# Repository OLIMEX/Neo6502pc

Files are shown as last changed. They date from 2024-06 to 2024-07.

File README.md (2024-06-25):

# Neo6502pc
World fastest 6502 computer. All in one Open Source Hardware and Software Modern Retro computer with real 6502 processor, HDMI, USB Flash drive, USB Gamepads, mouse, Keyboard support.

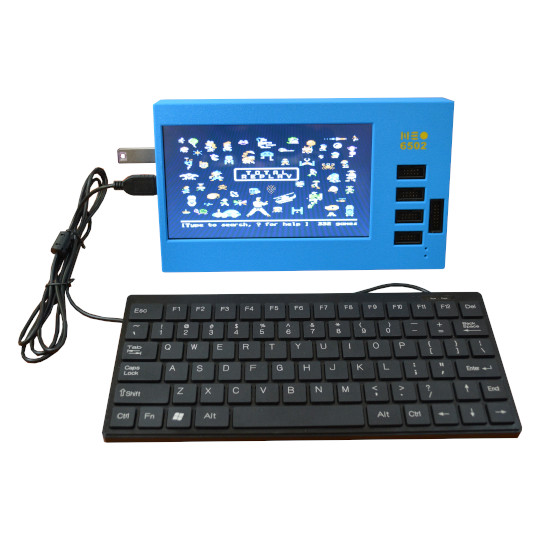
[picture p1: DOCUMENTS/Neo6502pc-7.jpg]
Neo6502pc-1


https://www.olimex.com/Products/Retro-Computers/Neo6502pc/open-source-hardware

## Licensee
* Hardware is released under CERN Open Hardware Licence Version 2 - Strongly Reciprocal
* Software is released under GPL V3 Licensee
* Documentation is released under CC BY-SA 4.0

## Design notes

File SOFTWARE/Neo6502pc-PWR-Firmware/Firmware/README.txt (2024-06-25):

### Install - packages
apt-get install build-essential libnewlib-dev gcc-riscv64-unknown-elf libusb-1.0-0-dev libudev-dev gdb-multiarch

### Install - Visual Studio Code 
https://code.visualstudio.com/docs/setup/linux

### Install - Platform IO 
https://platformio.org/install/ide?install=vscode

### Install - CH32V-Platform
https://github.com/Community-PIO-CH32V/ch32-pio-projects?tab=readme-ov-file#installing-the-ch32v-platform

To build firmware.bin and firmware.elf select 
> PlatformIO > PROJECT TASKS > Default > Advanced > Verbose build

Usage
===================================

I2C address - 0x33

Registers
-----------------------------------
0x00 - API version (major)
0x01 - API version (minor)
0x02 - Pin select
0x03 - GPIO config
       0x00 - output open drain
       0x01 - output push pull
       0x80 - input float
       0x81 - input pull down
       0x82 - input pull up
0x04 - Data
0x05 - Pins as bits MSB 
0x06 - Pins as bits LSB 
0x07 - BATSENS in percent 
0x08 - BATSENS in mV MSB 
0x09 - BATSENS in mV LSB 

All pins are initally configured as inputs pull down.
NOTE: Valid pins are from 3 to 14. 
NOTE: Virtual pin 15 is PWRSENS.
NOTE: VBAT range 3.2V - 4.2V => BATSENS range 0.89V - 1.14V

To change configuration:
------------------------
1. Write to register 0x02 (Pin select) pin you want to configure
2. Write to register 0x03 (GPIO config) desired config value

To get pin state:
-----------------
1. Write to register 0x02 (Pin select) pin you want to check
2. Read register 0x04 (Data)
If the pin is configured as input (default) readed value is current pin state
If the pin is configured as output the value is last set state

To change pin state:
--------------------
1. Write to register 0x02 (Pin select) pin you want to change
2. Write to register 0x04 (Data) desired new state
If the pin is configured as input (default) nothing will be done
If the pin is configured as output the pin state will be set

Alternative method:
--------------------
You can use registers 0x05 and 0x06 to get/set pin state at once
Register 0x05 contains MSB - pins 15 - 8
Register 0x06 contains LSB - pins  7 - 0

NOTE: Valid pins are from 3 to 14.
NOTE: Virtual pin 15 is PWRSENS.

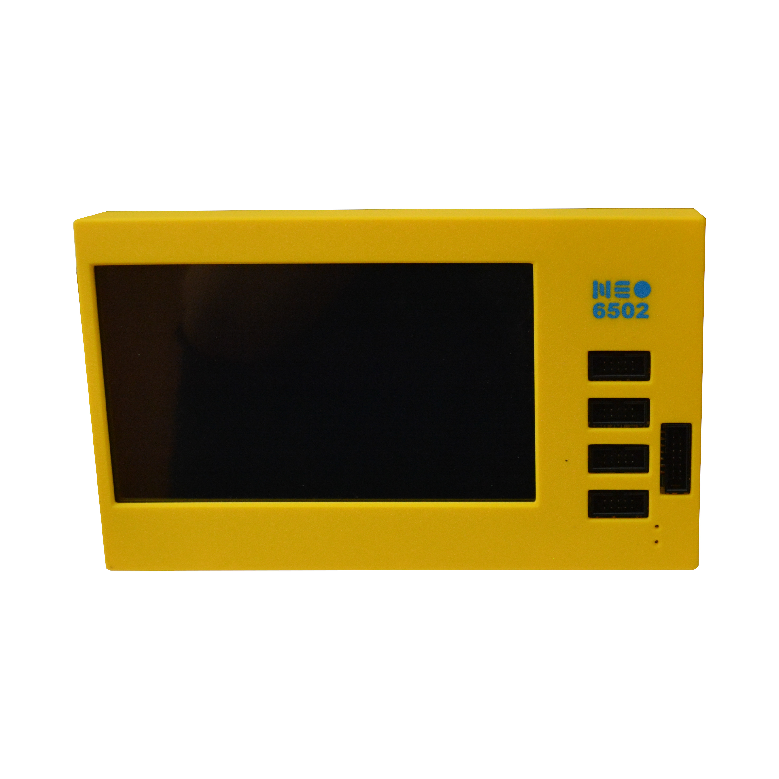
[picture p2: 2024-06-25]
DOCUMENTS/Neo6502pc-9.jpg

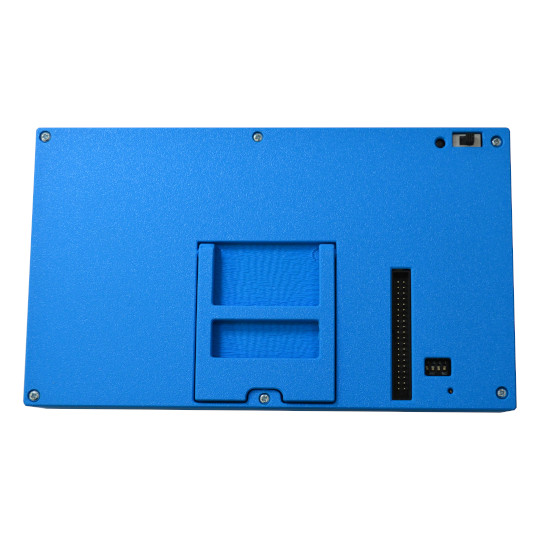
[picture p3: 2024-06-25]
DOCUMENTS/Neo6502pc-2.jpg

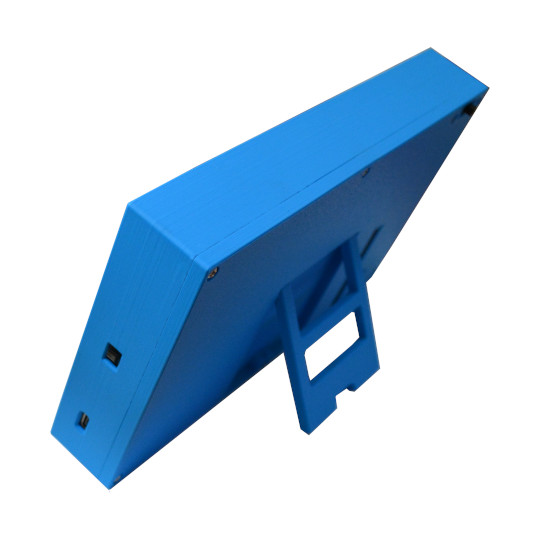
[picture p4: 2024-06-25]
DOCUMENTS/Neo6502pc-5.jpg

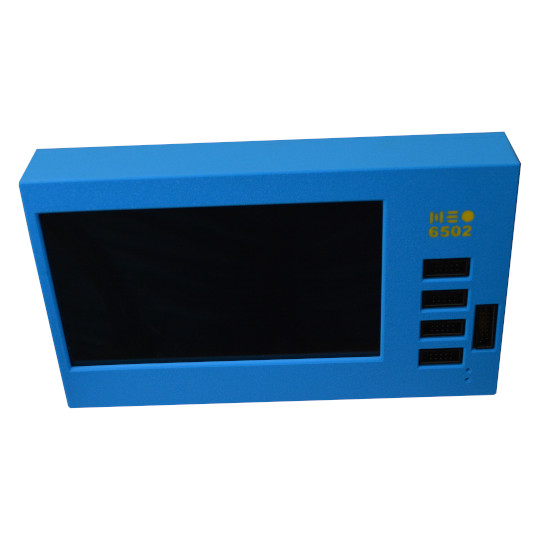
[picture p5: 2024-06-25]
DOCUMENTS/Neo6502pc-6.jpg

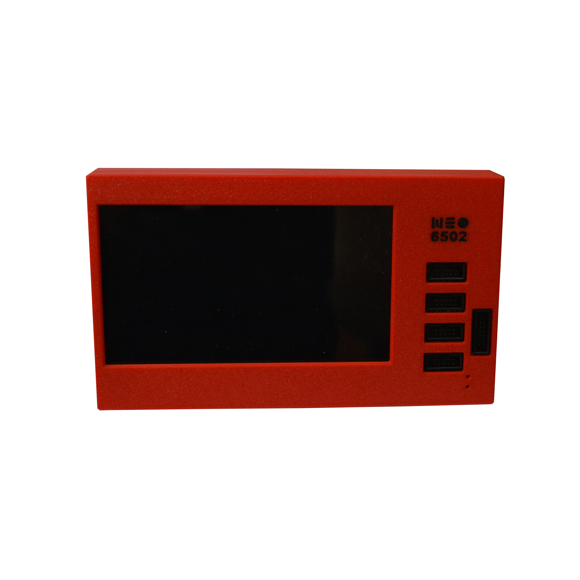
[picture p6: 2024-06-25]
DOCUMENTS/Neo6502pc-10.jpg

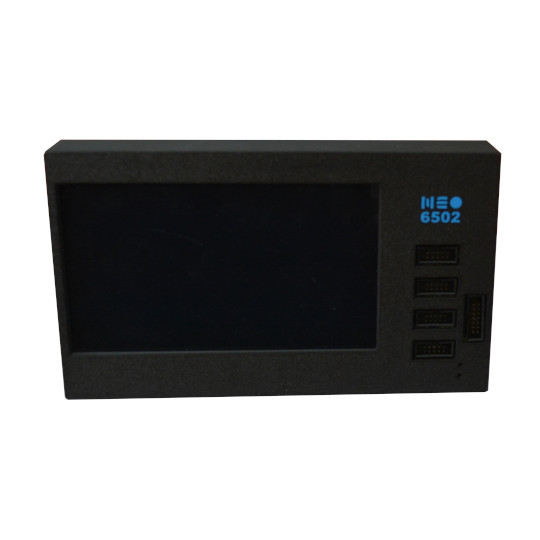
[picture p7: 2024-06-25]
DOCUMENTS/Neo6502pc-11.jpg

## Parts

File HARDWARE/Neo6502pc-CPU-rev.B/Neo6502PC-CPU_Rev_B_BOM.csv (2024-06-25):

Quantity | Value | Footprint | Reference
1 | PJ-3.5-365-5P | SCJ325P00XG0B02G | AUDIO1
1 | T1102D(6x6x9.5mm) | T1102D_6x6 | BOOT1
1 | P-B-V-40-LF | GBH-254-SMT-40 | BUS1
19 | 100nF/10V/20%/X5R/C0402 | C_0402_5MIL_DWS | C1, C2, C3, C4, C5, C6, C7, C8, C9, C10, C13, C14, C20, C24, C30, C31, C33, C34, C36
5 | 2.2uF/6.3V/20%/X5R/C0402 | C_0402_5MIL_DWS | C11, C12, C32, C35, C37
2 | 18pF/50V/5%/C0G/C0402 | C_0402_5MIL_DWS | C15, C16
3 | 47uF/6.3V/20%/X5R/C0805 | C_0805_5MIL_DWS | C17, C27, C28
1 | 1uF/10V/10%/X5R/C0603 | C_0603_5MIL_DWS | C18
1 | 10uF/6.3V/20%/X5R/C0603 | C_0603_5MIL_DWS | C19
2 | 22uF/6.3V/20%/X5R/C0603 | C_0603_5MIL_DWS | C23, C29
1 | CABLE PH2.0-3 | Cable-IDC | Cable-PWR1
1 | pUEXT-CABLE-10-10-200MM | Cable-IDC | Cable-pUEXT1
1 | 1N4148W/SOD123 | SOD-123_1C-2A_KA | D1
1 | HDMI-SWM-19 | HDMI-SWM-19_Paste | DVI1
1 | FSMD035-1206 | FUSE-1206 | FUSE1
1 | SS-12D10L5 | SS-12D10L5 | HUB_RST_OFF/ON1
1 | PH2.0-3PWB | PH2.0-3PWB | PWR_In/Out1
2 | Q12MHz/20pF/10ppm/4P/3.2x2.5mm | TSX-3.2x2.5mm_GND(3) | Q1, Q3
1 | BC817-40(SOT23) | SOT23 | Q2
10 | 10k/R0402 | R_0402_5MIL_DWS | R1, R12, R13, R14, R15, R16, R17, R26, R27, R28
2 | 100R/R0402 | R_0402_5MIL_DWS | R3, R6
2 | 27R/R0402 | R_0402_5MIL_DWS | R4, R5
1 | 33k/R0402 | R_0402_5MIL_DWS | R7
1 | 150R/R0402 | R_0402_5MIL_DWS | R8
1 | 47R/R1206 | R_1206_5MIL_DWS | R9
3 | 2.2k/R0402 | R_0402_5MIL_DWS | R10, R29, R30
9 | 270R/R0402 | R_0402_5MIL_DWS | R11, R18, R19, R20, R21, R22, R23, R24, R25
2 | 5.1k/1%/R0402 | R_0402_5MIL_DWS | R31, R32
2 | RA1206_(4x0603)_4B8_330R | RA1206_(4X0603)_4B8_xx | RM1, RM2
1 | Speaker_QMB-09B-03(1.5-5.0V_2.7kHz_F9.0mm*H5.5mm) | Speaker_QMB-09B-03_1-Plus_2-Minus | SPK1
1 | SLIDE SWITCH DM-04 | SLIDE_SWITCH_DM-04(Step_2.54mm) | SWITCH1
1 | ZD25Q16BTIGT(SOIC-8_208mils) | SO-8_208mil | U1
1 | RP2040(QFN-56_7x7mm_P0.4mm) | QFN56_7x7_Pitch_0.4mm | U2
1 | CH217K(SOT23-6L) | SOT23-6 | U3
1 | CH334S(SSOP-28) | SSOP28 | U4
1 | W65C02S6TQTG-14(TQFP44) | TQFP44_NEO6502 | U5
3 | 74LVC245APW(TSSOP20) | TSSOP20_Pitch-0.65mm_6.6x4.5x1.2mm | U6, U7, U8
4 | USB-A-SMT-6.3H | USB-A-SMT-6.3H_HOST_Female | USB-HOST2, USB-HOST3, USB-HOST4, USB-PWR_Out1
1 | USB-C-16P-F(A40-00119-A52-12) | USB2.0_TYPE-C(A40-00119-A52-12)_Paste | USB-PGM1
1 | SH1.0-10P-90D | SM10B-SRSS-TB | pUEXT1

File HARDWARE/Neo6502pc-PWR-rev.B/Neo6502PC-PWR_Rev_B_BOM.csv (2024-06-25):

Quantity | Value | Footprint | Reference
1 | PH2.0-2PWB | PH2.0-2PWB | BAT1
2 | 100nF/10V/20%/X5R/C0402 | C_0402_5MIL_DWS | C1, C12
5 | 22uF/6.3V/20%/X5R/C0603 | C_0603_5MIL_DWS | C2, C5, C6, C8, C10
1 | LED/YELLOW/0603 | LED_0603_KA | CHARGING1
3 | 1N5822/SS34/SMA | SMA-KA | D2, D3, D4
1 | B-V-14-LF | GBH-254-SMT-14 | EXT1
1 | WPM2015-3/TR | SOT23 | FET1
1 | 2.2uH/3A/YS75/7x8 | YS75_7X8MM | L1
1 | 1.0uH/2.5A/DCR=30mR/20%/3.00x3.00x1.50mm/CD32(SWPA3015S1R0MT) | CD32 | L2
1 | PH2.0-3PWB | PH2.0-3PWB | PWR_In/Out1
1 | LED/RED/0603 | LED_0603_KA | PWR_LED1
1 | SS-12D11G5 | SS-12D11G5 | PWR_OFF/ON1
2 | 2.2k/R0402 | R_0402_5MIL_DWS | R1, R3
4 | 10k/R0402 | R_0402_5MIL_DWS | R2, R4, R15, R17
2 | 5.1k/1%/R0402 | R_0402_5MIL_DWS | R5, R6
1 | 8.25k/1%/R0402 | R_0402_5MIL_DWS | R7
1 | 1.05k/1%/R0402 | R_0402_5MIL_DWS | R8
2 | 220k/R0402 | R_0402_5MIL_DWS | R9, R11
1 | 49.9k/1%/R0402 | R_0402_5MIL_DWS | R10
2 | 470k/R0402 | R_0402_5MIL_DWS | R12, R13
1 | 150k/R0402 | R_0402_5MIL_DWS | R14
1 | BL4054B-42TPRN(SOT23-5) | SOT-23-5 | U1
1 | CH32V003F4P6(TSSOP20) | TSSOP20_Pitch-0.65mm_6.6x4.5x1.2mm | U2
1 | TPS62A02ADRLR(SOT-563-6) | SOT-563-6 | U3
1 | MT3608(SOT23-6) | SOT23-6 | U4
4 | P-B-V-10-LF | GBH-254-SMT-10 | UEXT1, UEXT2, UEXT3, UEXT4
1 | USB-C-16P-F(A40-00119-A52-12) | USB2.0_TYPE-C(A40-00119-A52-12)_Paste | USB-PWR_In1
1 | SH1.0-10P-90D | SM10B-SRSS-TB | pUEXT1

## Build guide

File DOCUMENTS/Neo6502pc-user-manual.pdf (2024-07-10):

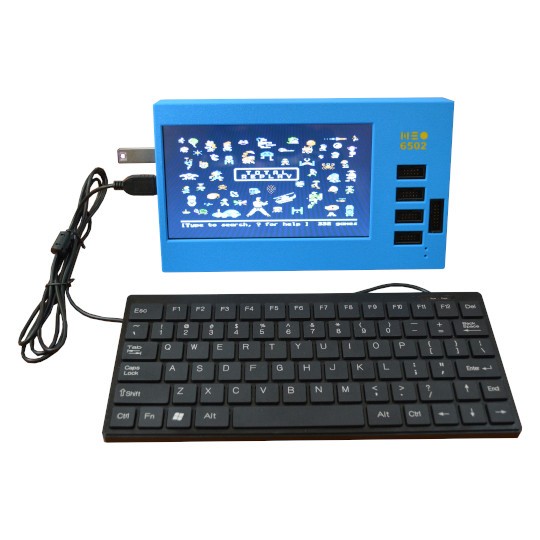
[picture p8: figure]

# Neo6502pc

# User Manual

Rev.1.0 June 2024 | olimex.com

Table of Contents

Introduction to Neo6502pc

Neo6502pc open source software and hardware stand alone computer based on W65C02 processor and RP2040 co-processor with the following features:

- real W65C02 processor clocked at 6.25Mhz
- graphics co-processor RP2040 which generates HDMI video
- 320 x 240 256 colour display on HDMI/DVI with a palette
- 32k Graphics RAM for tiles and sprites
- 128 sprites up to 32x32 pixels.
- Multiple tile maps (16x16 tiles, can be double sized)
- High speed drawing features
- Turtle Graphics
- Blitter for high speed graphics
- UEXT interface to access a wide range of hardware add ons.
- 1 channel "beeper" sound with SFX library (to be replaced by AY-3-8910 Emulation)
- Storage USB Key (optionally can use SD Card)
- standard USB keyboard can be connected to Neo6502pc
- Fast structured BASIC with hardware support and inline assembler.
- BASIC can be edited on screen, or using a text editor.
- High Speed Integer/Floating point arithmetic
- Documentation, samples, explainers and games, all open source.
- Cross development support
- Accurate cross platform emulator for Windows/Mac/Linux, only requires SDL2
- Serial link to PC for Cross-Development
- Program in PASCAL using Mad Pascal compiler
- Program in 'C' using CC65 and LLVM
- USB Mouse and Gamepad support

- BASIC support for Serial, I2C and SPI hardware via UEXT Connector- 64KB linear RAM space for code
- LCD display
- internal battery backup power supply which allow it to operate up to 3 hours without external power supply
- three external and one internal USB hosts (internal is connected to LCD touch panel)
- Audio output
- four UEXT connectors for different peripherals
- 12 GPIO extension connector
- USB-C for power and internal battery charger
- second USB-C for RP2040 firmware programming
- Dimensions 220 x 130 x 35 mm

The design goal with Neo6502 was to make simple modern retro computer with 6502 processor.

By modern we mean computer with modern video interface like HDMI, USB keyboard and USB Flash drive as storage. HDMI as everyone have TV with HDMI at home and USB keyboards now are mainstream device for input.

With the task to provide HDMI and USB interface we choose RP2040 which already have DVI bit bang project and USB host.

RP2040 also have enough RAM so we decided to use RP2040 to emulate also the RAM memory for 6502.

For the 6502 processor we choose W65C02 from WDC as they are still in mass production and can be purchased freely.

The Neo name was taken for two reasons, first it imply the modern design, then we liked the analogy with the movie The Matrix as W65C02 lives in virtual world and thinks it have real memory, video and keyboard but actually all this is virtual and emulated by RP2040.

Neo6502 is Open Source Hardware, all CAD files and firmware and available, so people can study and modify.

Latest Neo6502 (not Neo6502pc) manual is available here. (https://neo6502.com/pdf/document.pdf) Everything for Neo6502 apply for Neo6502pc which is all in one Neo6502 computer with display and build in USB hub.

Order codes for Neo6502pc and accessories:

Neo650 (https://www.olimex.com/Products/Retro-Computers/Neo6502pc/open-source-hardware) 2pc (https://www.olimex.com/Products/Retro-Computers/Neo6502pc/open-source-hardware) | All in one complete stand alone computer operating from external supply or

internal LiPo rechargable battery

CABLE-USB-A-C-1M (https://www.olimex.com/Products/Components/Cables/CABLE-USB-A-C-1M/) USB-C cable for power supply

USB-FLASH-8GB (https://www.olimex.com/Products/Components/Storage/USB-FLASH-8GB-THN-U202W0080E4/) USB Flash drive for Neo6502pc

USB-KEYBOARD-PS2 (https://www.olimex.com/Products/USB-Modules/USB-KEYBOARD-PS2/) USB keyboard with small dimensions suitable for Neo6502pc

USB-GAMEPAD (https://www.olimex.com/Products/Retro-Computers/USB-GAMEPAD/) | Wired USB gamepad compatible with NeoBASIC
USB-WIRELESS-GAMEPAD (https://www.olimex.com/Products/Retro-Computers/USB-WIRELESS-GAMEPAD/) | Wireless USB gamepad compatible with NeoBASIC
UEXT modules (https://www.olimex.com/Products/Modules/) | many UEXT modules which can connect to Neo6502 UEXT connector

HARDWARE

Neo6502pc layout:

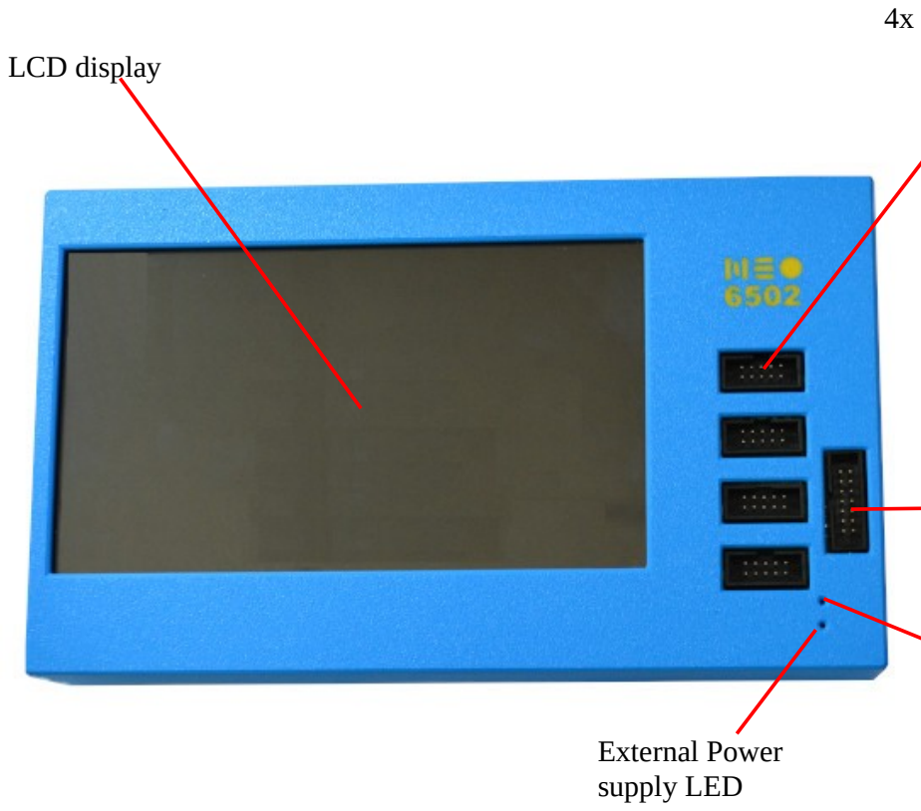
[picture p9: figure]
LCD display; External Power supply LED

4x UEXT connectors

EXT 12 GPIO

Battery charge
LED

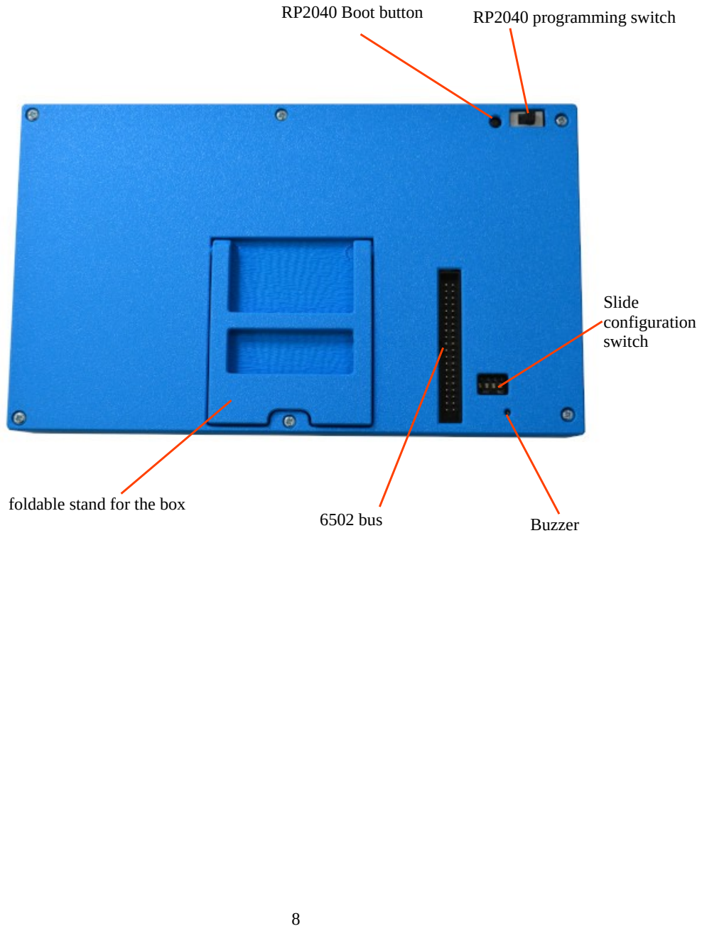
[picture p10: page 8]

foldable stand for the box

RP2040 Boot button | RP2040 programming switch

Slide
configuration
switch

Buzzer 6502 bus

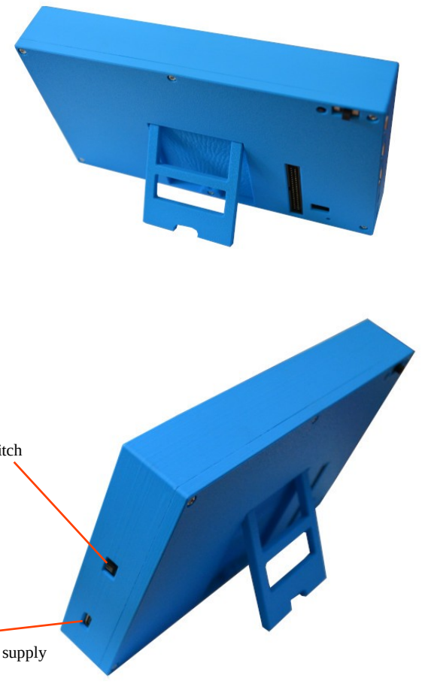
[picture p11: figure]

ON-OFF switch

USB-C for external power supply

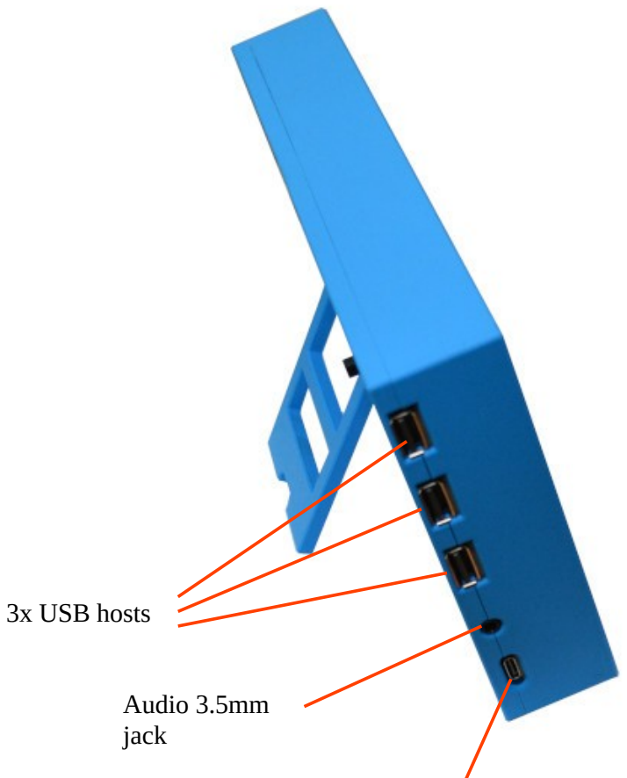
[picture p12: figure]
3x USB hosts; Audio 3.5mm jack

RP2040 programming
USB-C connector

Neo6502pc can be ordered in 5 colors: Red, Blue, Green, Yellow, Black.

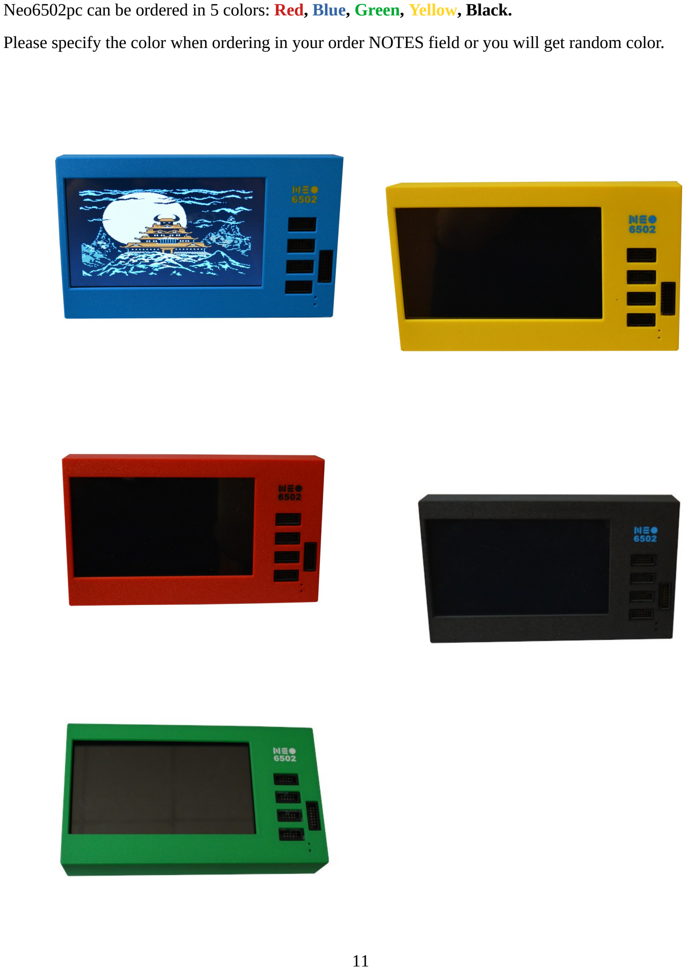
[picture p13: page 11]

Please specify the color when ordering in your order NOTES field or you will get random color.

Neo6502pc 6502 bus connector:

All 6502 signals are available on BUS1 connector for attaching external hardware on it.

+5V, 3.3V, GND

D0-D7, A0-A15, PHI2, R/W, RESB, SOB, MLB, VPB, SYNC, NMIB, IRQB

Two signals of RP2040 SWDIO SWCLK are also present for RP2040 debugging, these should be N.C. on the external 6502 peripheral boards.

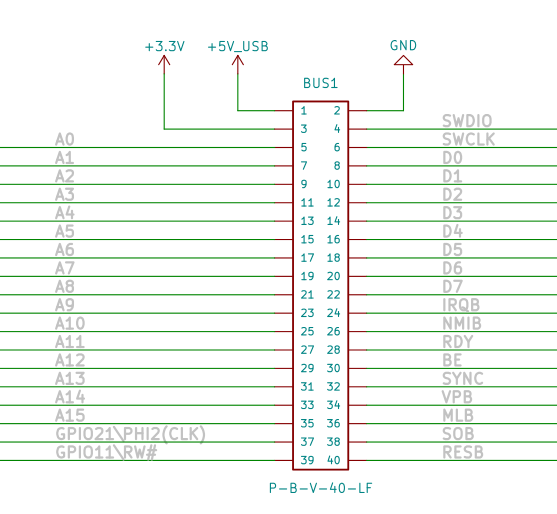
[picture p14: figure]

Neo6502pc schematics:

Neo6502pc latest schematic is on GitHub (https://github.com/OLIMEX/Neo6502pc)

UEXT connector:

UEXT connector stands for Universal EXTension connector and contain +3.3V, GND, I2C, SPI, UART signals.

UEXT connector can be in different shapes.

The original UEXT connector is 0.1” 2.54mm step boxed plastic connector. All signals are with 3.3V levels.

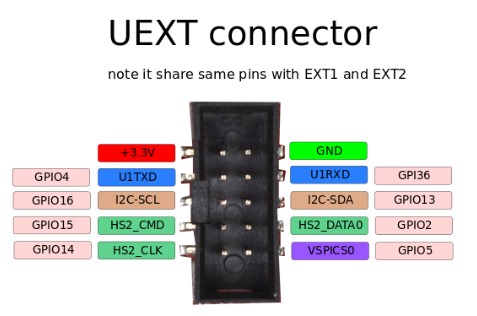
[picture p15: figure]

Olimex has developed number of MODULES (https://www.olimex.com/Products/Modules/) with this connector. There are temperature, humidity, pressure, magnetic field, light sensors. Modules with LCDs, LED matrix, Relays, Bluetooth, Zigbee, WiFi, GSM, GPS, RFID, RTC, EKG, sensors and etc.

Neo6502pc UEXT connector is wired to RP2040 GPIOs as follows:

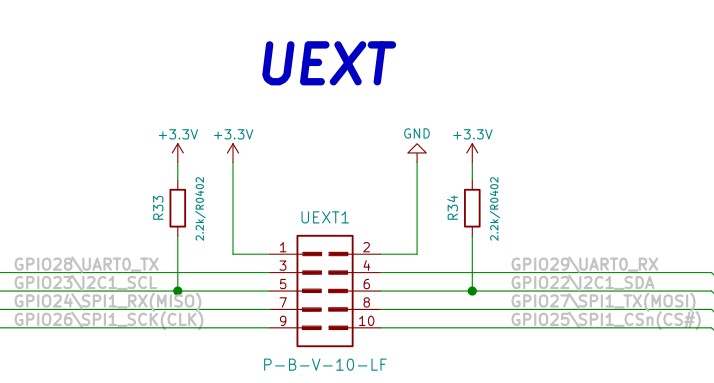
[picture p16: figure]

SLIDE Configuration Switch

The Slide configuration switch can enable/disable the Buzzer, also can connect or disconnect RESB, NMIB and IRQB to RP2040 UEXT signals.

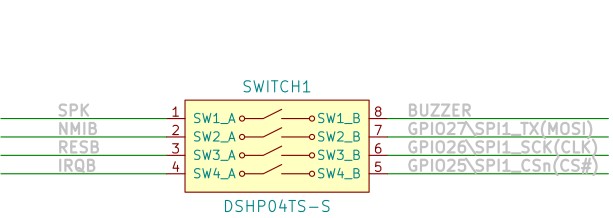
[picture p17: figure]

By default Neo6502 is shipped with all sections connected on the switch i.e. buzzer is enabled and all signals are wired to RP2040. This means you can’t use SPI on UEXT connector if you do not disconnect these signals.

### 12 GPIO EXT1 connector:

Neo6502pc have CH32V003 expander IC which is connected to RP2040 via I2C and can monitor battery charge, if the external power supply is present or to access 12 GPIOs to EXT1 connector:

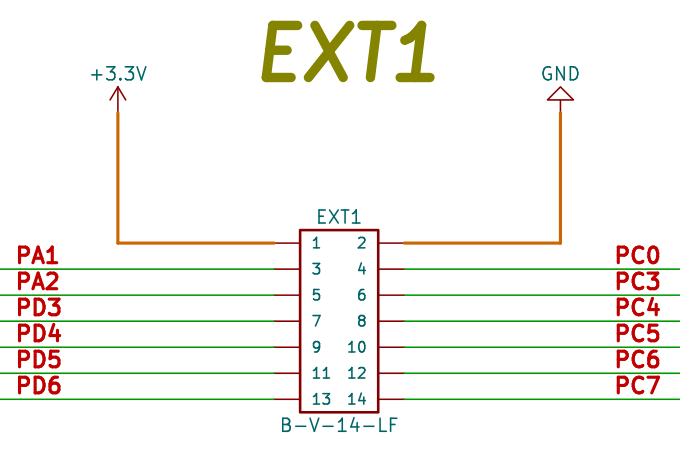
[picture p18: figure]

SOFTWARE:

Neo6502 is open flexible system as everything is virtual and depend on RP2040 firmware, this allow you to emulate old architectures like Apple ][ and Oric Atmos, or to make your own completely new architecture.

Veselin Sladkov (veselin.sladkov@gmail.com) did amazing work for Neo6502 and created Apple ][, Oric Atmos and Apple Iic emulation with Reload emulator. (https://github.com/vsladkov/reload-emulator)

The reload emulator require some ROMs and disks which are hosted on olimex’s ftp. (https://ftp.olimex.com/Neo6502/)

Paul Robson (paul@robsons.org.uk ) made special version of Neo6502 Basic on GitHub (https://github.com/paulscottrobson/neo6502) and web browser emulator. (http://www.robsons.org.uk/neo6502/neo.html)

Default software Apple][e amulator with Total Replay 5.1:

We ship Neo6502pc with Apple][e emulator programmed in it, so all you need is USB keyboard and USB Flash drive to make it run 400+ old Apple games.

You can download the Total replay file from here. (http://ftp.olimex.com/Neo6502/Total%20Replay%20v5.1.hdv)

Programming RP2040

The RP2040 firmware is UF2 file. You can get pre-build firmware of reload emulator on olimex’s ftp.

1. The RP2040 firmware for the Apple][e emulator is here. (http://ftp.olimex.com/Neo6502/apple2e-5.uf2) But you do not have to program it as all Neo6502pc are shipped with it by default.
2. If you want to develop on Apple][e and write your own code you can program the firmware and the flash drive with blank ProDos disk from here. (http://ftp.olimex.com/Neo6502/blank_disk_for_apple2e_code_development_apple2e_ProDOS_2_4_3.zip) And Neo6502pc will boot as Apple][ and you can load and save your code on the Prodos disk (Flash drive).
3. For Oric Atmos we recommend you to use:

https://ftp.olimex.com/Neo6502/uf2/oric_960x540_372MHz.uf2

4. For NeoBASIC you need to go to Paul Robsol GitHub (https://github.com/paulscottrobson/neo6502-firmware) and download latest release files then to write to RP2040.

To program the .uf2 files you need two USB A to C cable.

Connect the first cable to USB and to the USB-C programming connector.

Conntect the second cable to USB or 5V charger and connect to USB-C power supply connector.

Move the PROGRAMMING slide switch on the back to outside direction (Program), press the BOOT button.

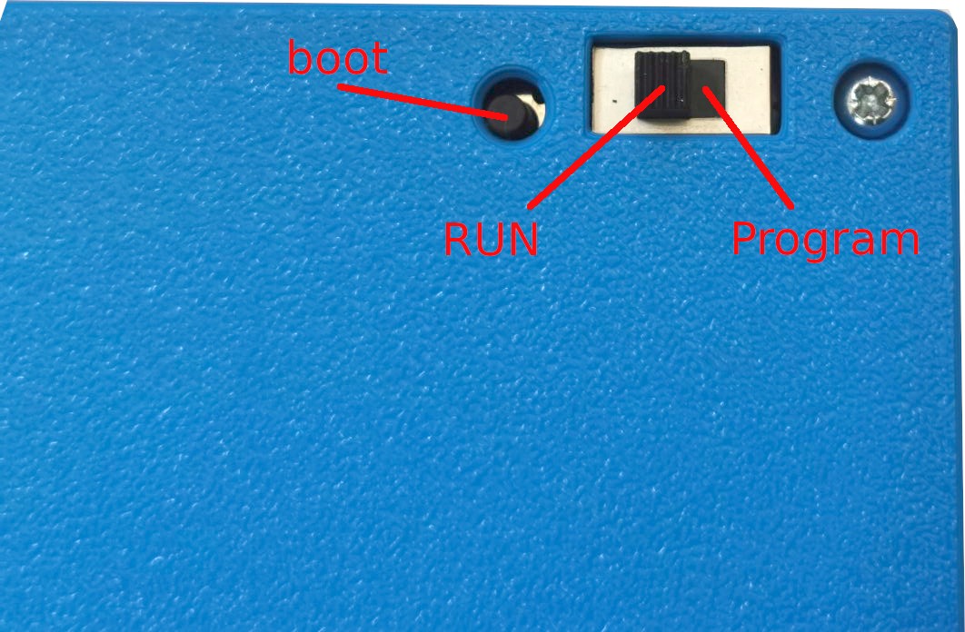
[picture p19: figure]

Switch the power ON and depress the boot button, you will see on your computer RP2 disk drive, drag and drop or copy the .ul2 file to this drive.

After the programming this drive will disappear, MOVE the PROGRAMMING switch to inner direction (RUN).

Some emulators require all sections of the Slide Configuration Switch to be in ON positon:

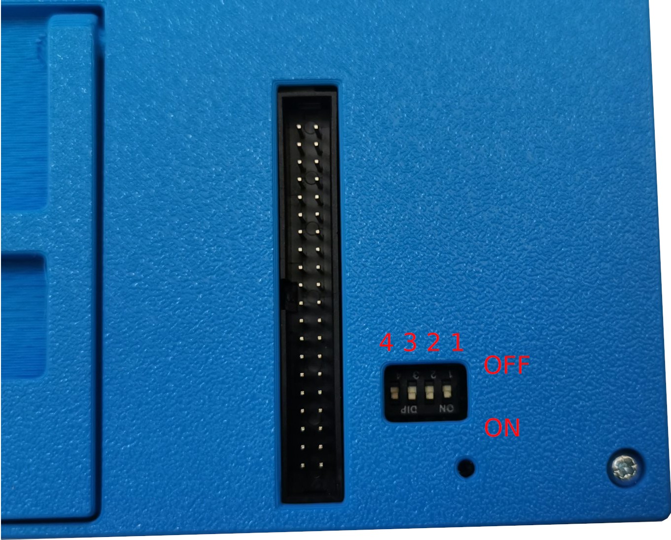
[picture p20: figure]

Revision History

Revision 1.0 June 2024

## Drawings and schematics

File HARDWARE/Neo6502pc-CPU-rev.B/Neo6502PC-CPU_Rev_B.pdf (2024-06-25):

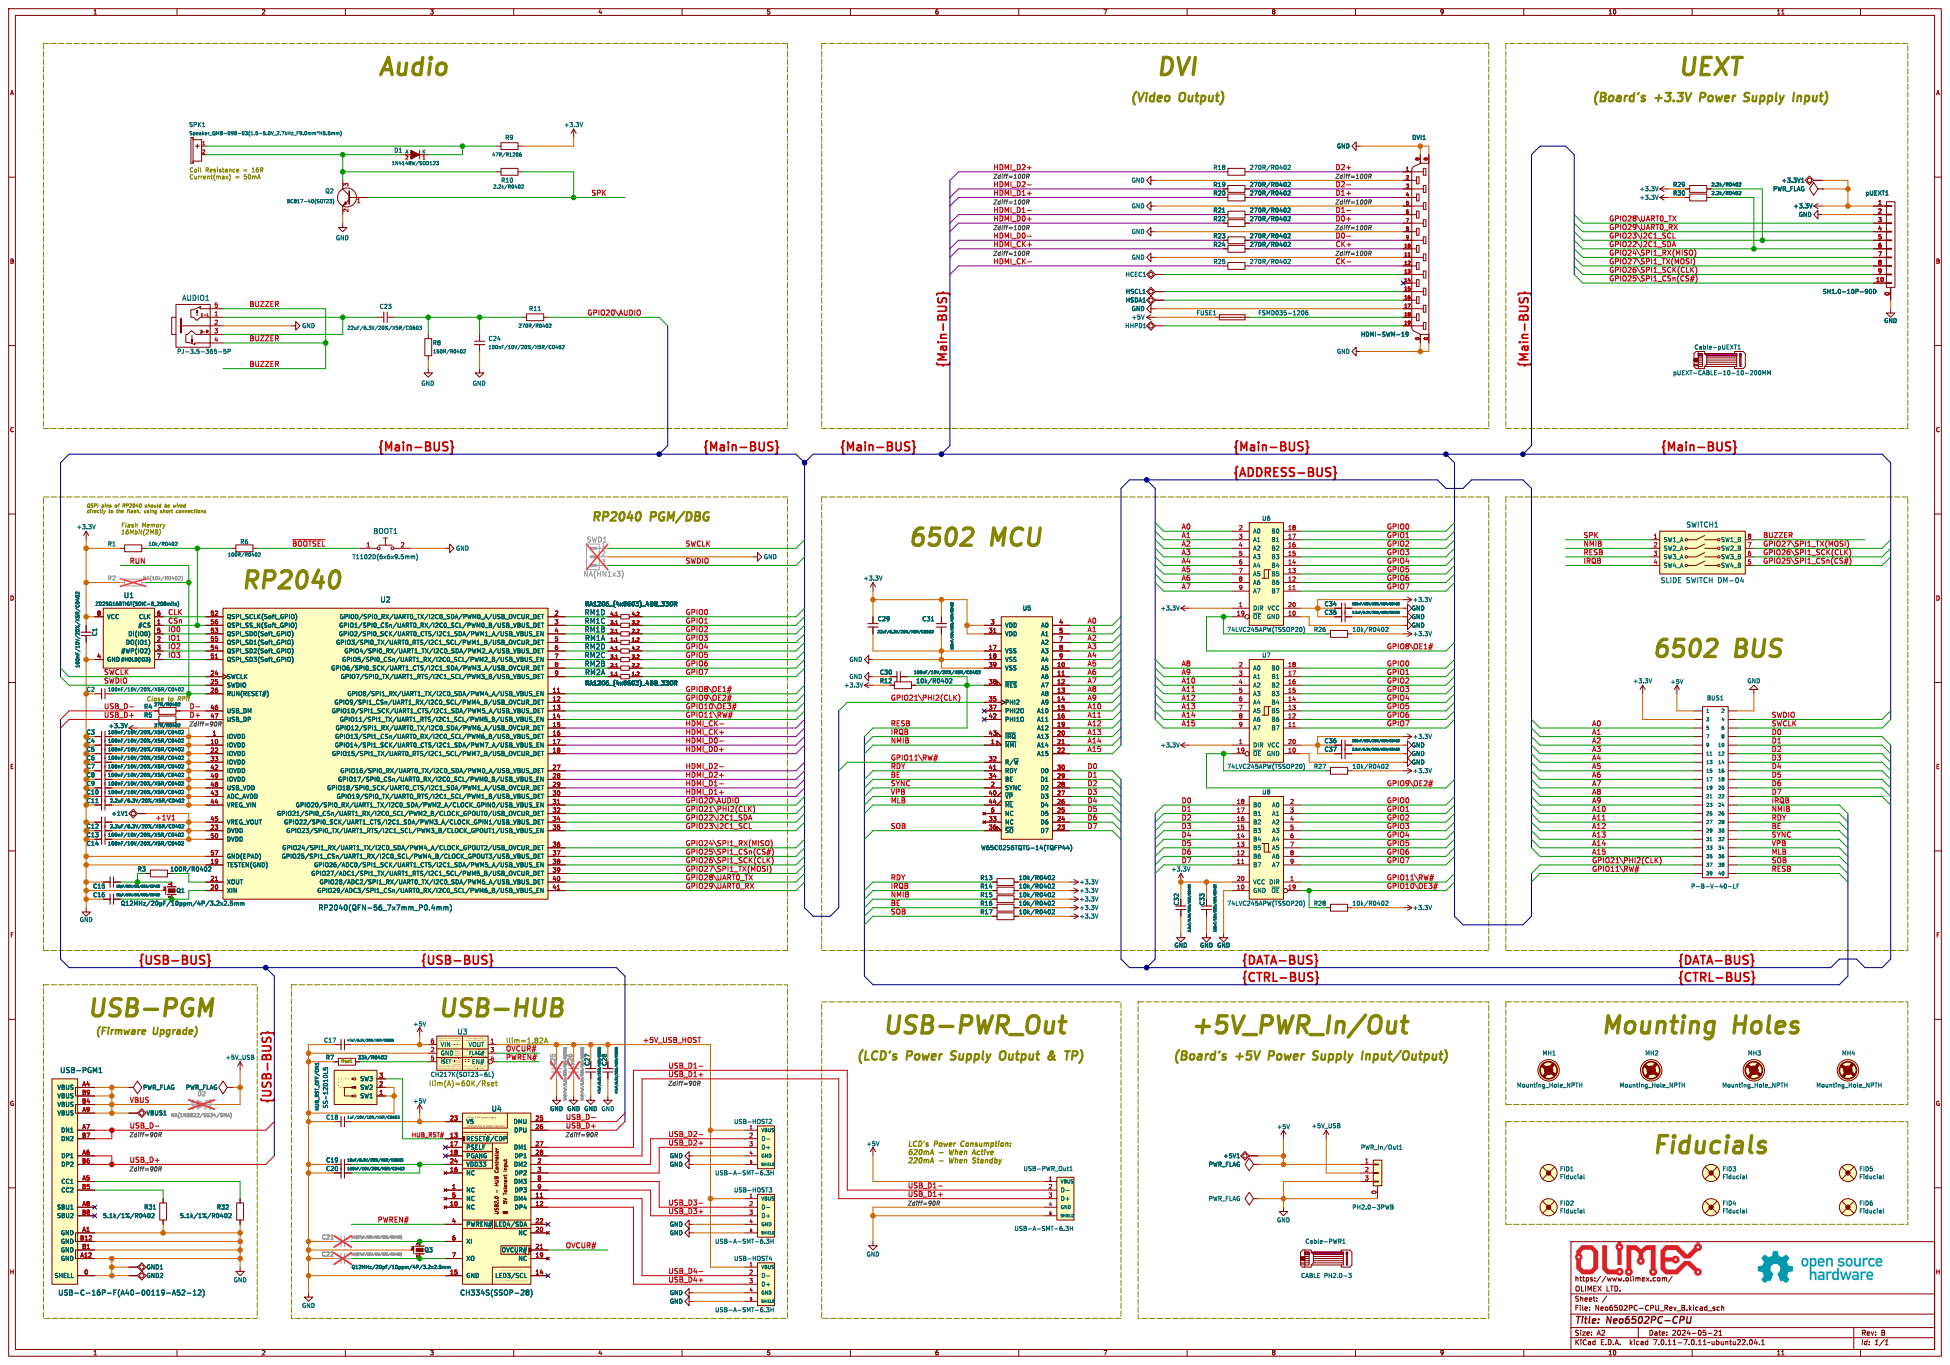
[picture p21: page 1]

(Board's +3.3V Power Supply Input)

QSPI pins of RP2040 should be wired

connectedto USBportVBUS Currentlimiting thresholdsetting, externalresistorRsetto GND to setIset ground

10uFor moreis recommended
alarmopen-drainoutput,activelow Common
terminal VIH=(1.8-5.0)V

(Board's +5V Power Supply Input/Output)

5 USB-HOST3 USB-A-SMT-6.3H GND GND GND

Configurepowerovercurrentprotectionmodeduringreset Configurepowersupplymodewith built-in pull-up resistor: defaulthigh level is self-powered,low level is setfor buspower External0.1uF+10uFdecouplingcapacitor,or 1uFdecouplingcapacitor external1uFor largercapacitor Externalresetinput with built-in pull-up resistor,activelow.

SCL:Outputfor EEPROMclock signalline duringreset SDA: EEPROMbi-directionaldatasignalline duringreset TheOVCUR#pin of CH334/5hasbuilt-in pull-up resistor(defaultOC_LEVEL=0).

File: Neo6502PC-CPU_Rev_B.kicad_sch Sheet: / OLIMEX LTD. https://www.olimex.com/

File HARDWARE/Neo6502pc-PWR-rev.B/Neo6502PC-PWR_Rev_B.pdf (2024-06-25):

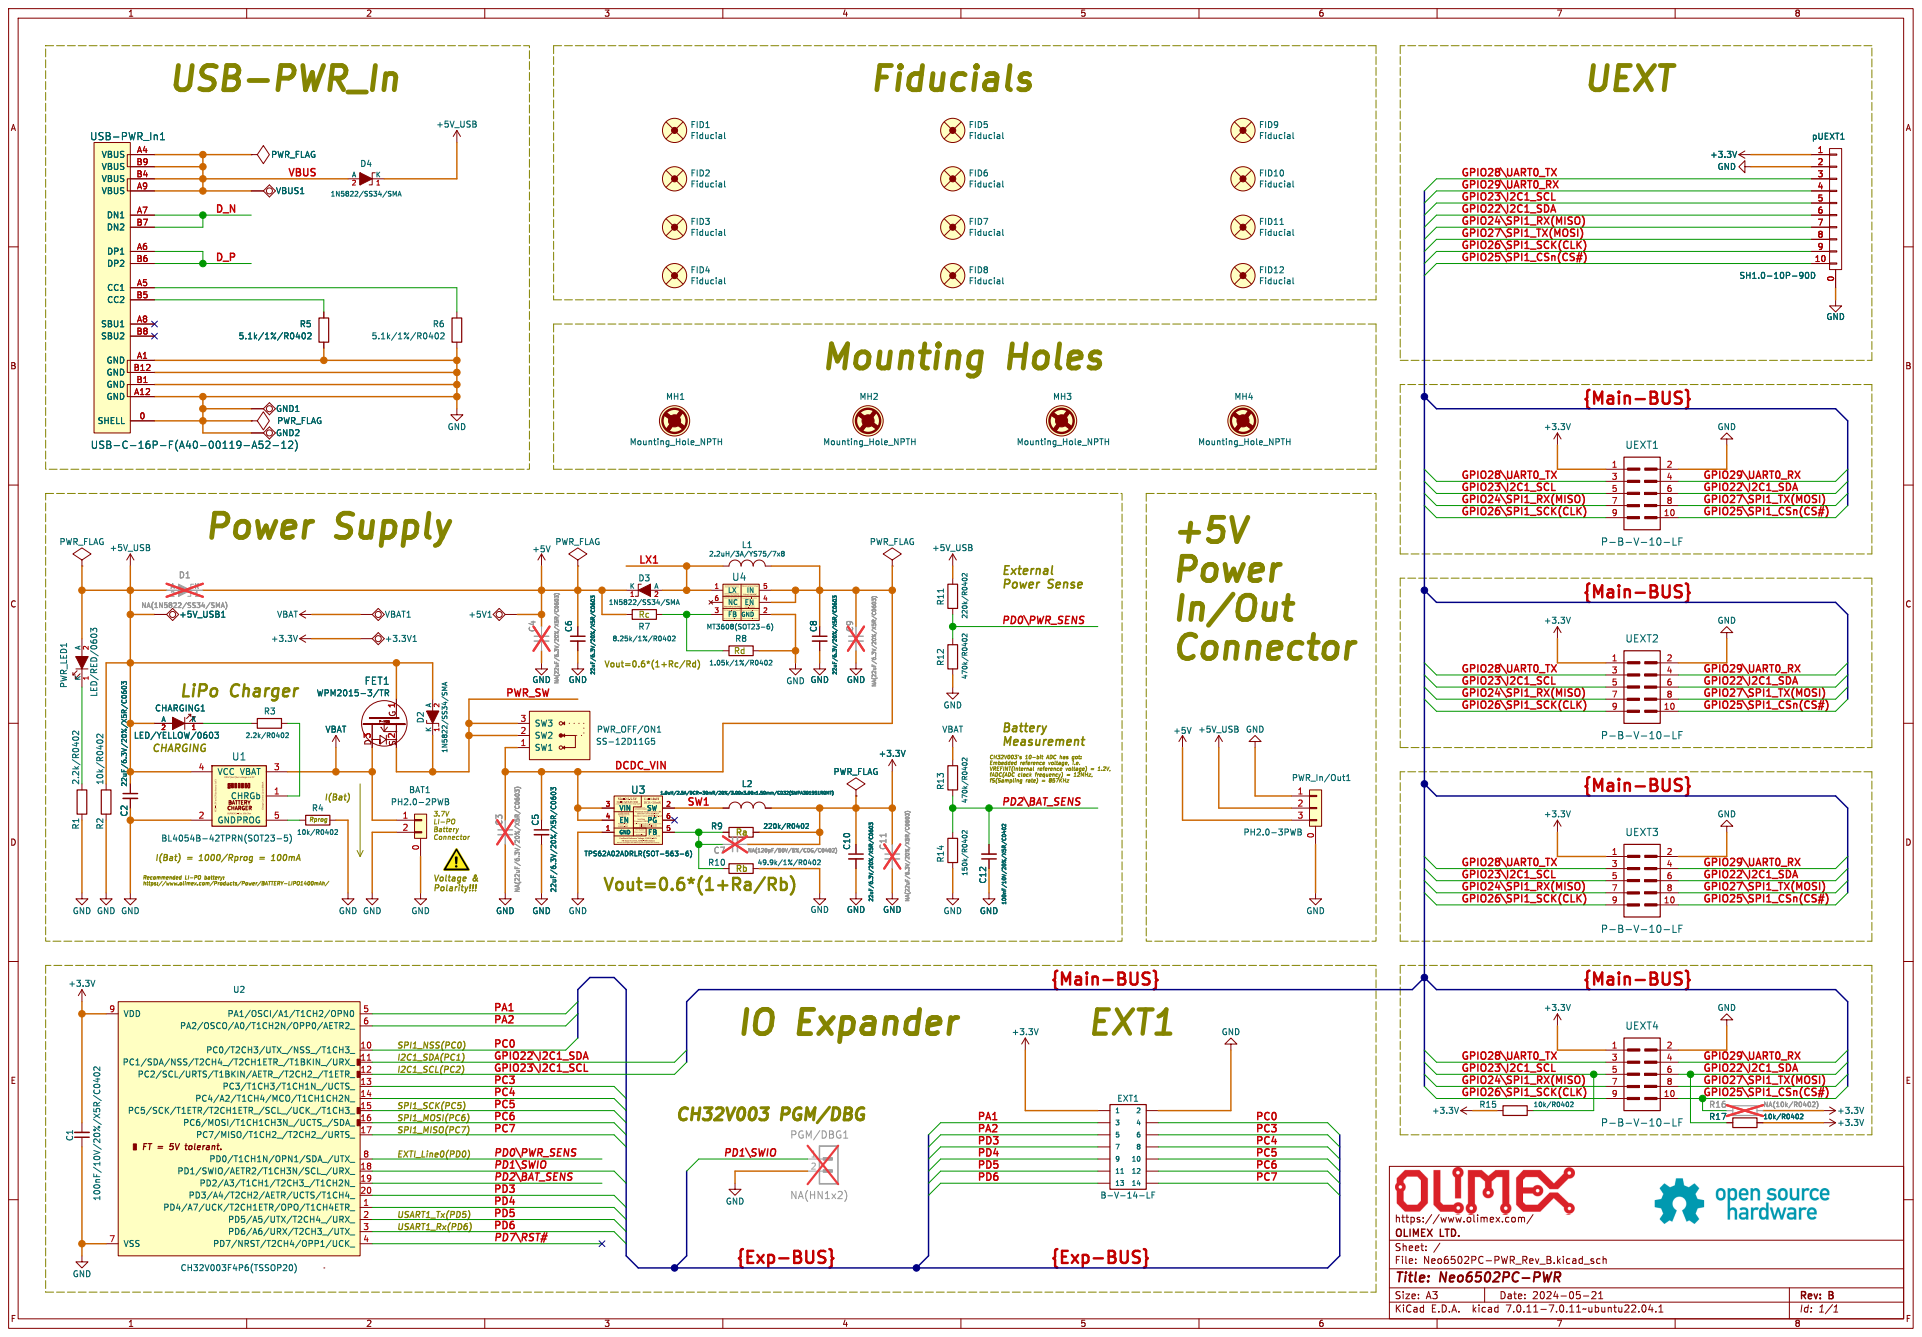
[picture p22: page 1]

FID11 Fiducial FID10 Fiducial FID9 Fiducial FID3 Fiducial FID1 Fiducial MH1 Mounting_Hole_NPTH
FID4 Fiducial FID2 Fiducial

Current(Shutdown)=1uA(Max) FB InputBiasCurrent=-50nA(min) FB Voltage=0.6V(Typical) OperatingInputVoltage

The inductorshouldhavelow corelossat 1.2MHz andlow DCR for betterefficiency. RecommendedInput/OutputCapacitors: 22uF/X5R(X7R). Schottkydiodeis a goodchoicefor MT3608

QuiescentCurrent(PFM)=200uA(Max) QuiescentCurrent(PWM)=2.2mA(Max) RecommendedInductorvalues:up to 22uH.

because of its low forwardvoltagedropandfast reversesrecovery. V(ENH)=1.5V(Min)

V(ENL)=0.4V(Max) Vin=(2-24)VDC

In casea loweroutputrippleisdesired,higheroutputcapacitancecanhelpreducetheripple. Lx=1.0uH
Cout=(10~22)uF/6.3V/X5Rþÿ(Vout"e1.8V). 22uFRecommended! Cout=22uF/6.3V/X5Rþÿ(1.2V"dVout<1.8V) Cout=44uF/6.3V/X5Rþÿ(0.6V"dVout<1.2V) DCR<50mR

Donotfloat. Enablecontrol. FB Input Current,I(FB)=100nA(max) FeedbackReferenceVoltage,V(REF)=0.6V
Rb mustnotbehigherthanþÿ100k© toprovideacceptablenoisesensitivity. ShutdownCurrentI(SHDN)=0.01-2uA
SwitchingFrequency 2.4MHz TPS62A02ADRLR V(ENH)=1.2V

{Main-BUS} PD7\RST# PD1\SWIO

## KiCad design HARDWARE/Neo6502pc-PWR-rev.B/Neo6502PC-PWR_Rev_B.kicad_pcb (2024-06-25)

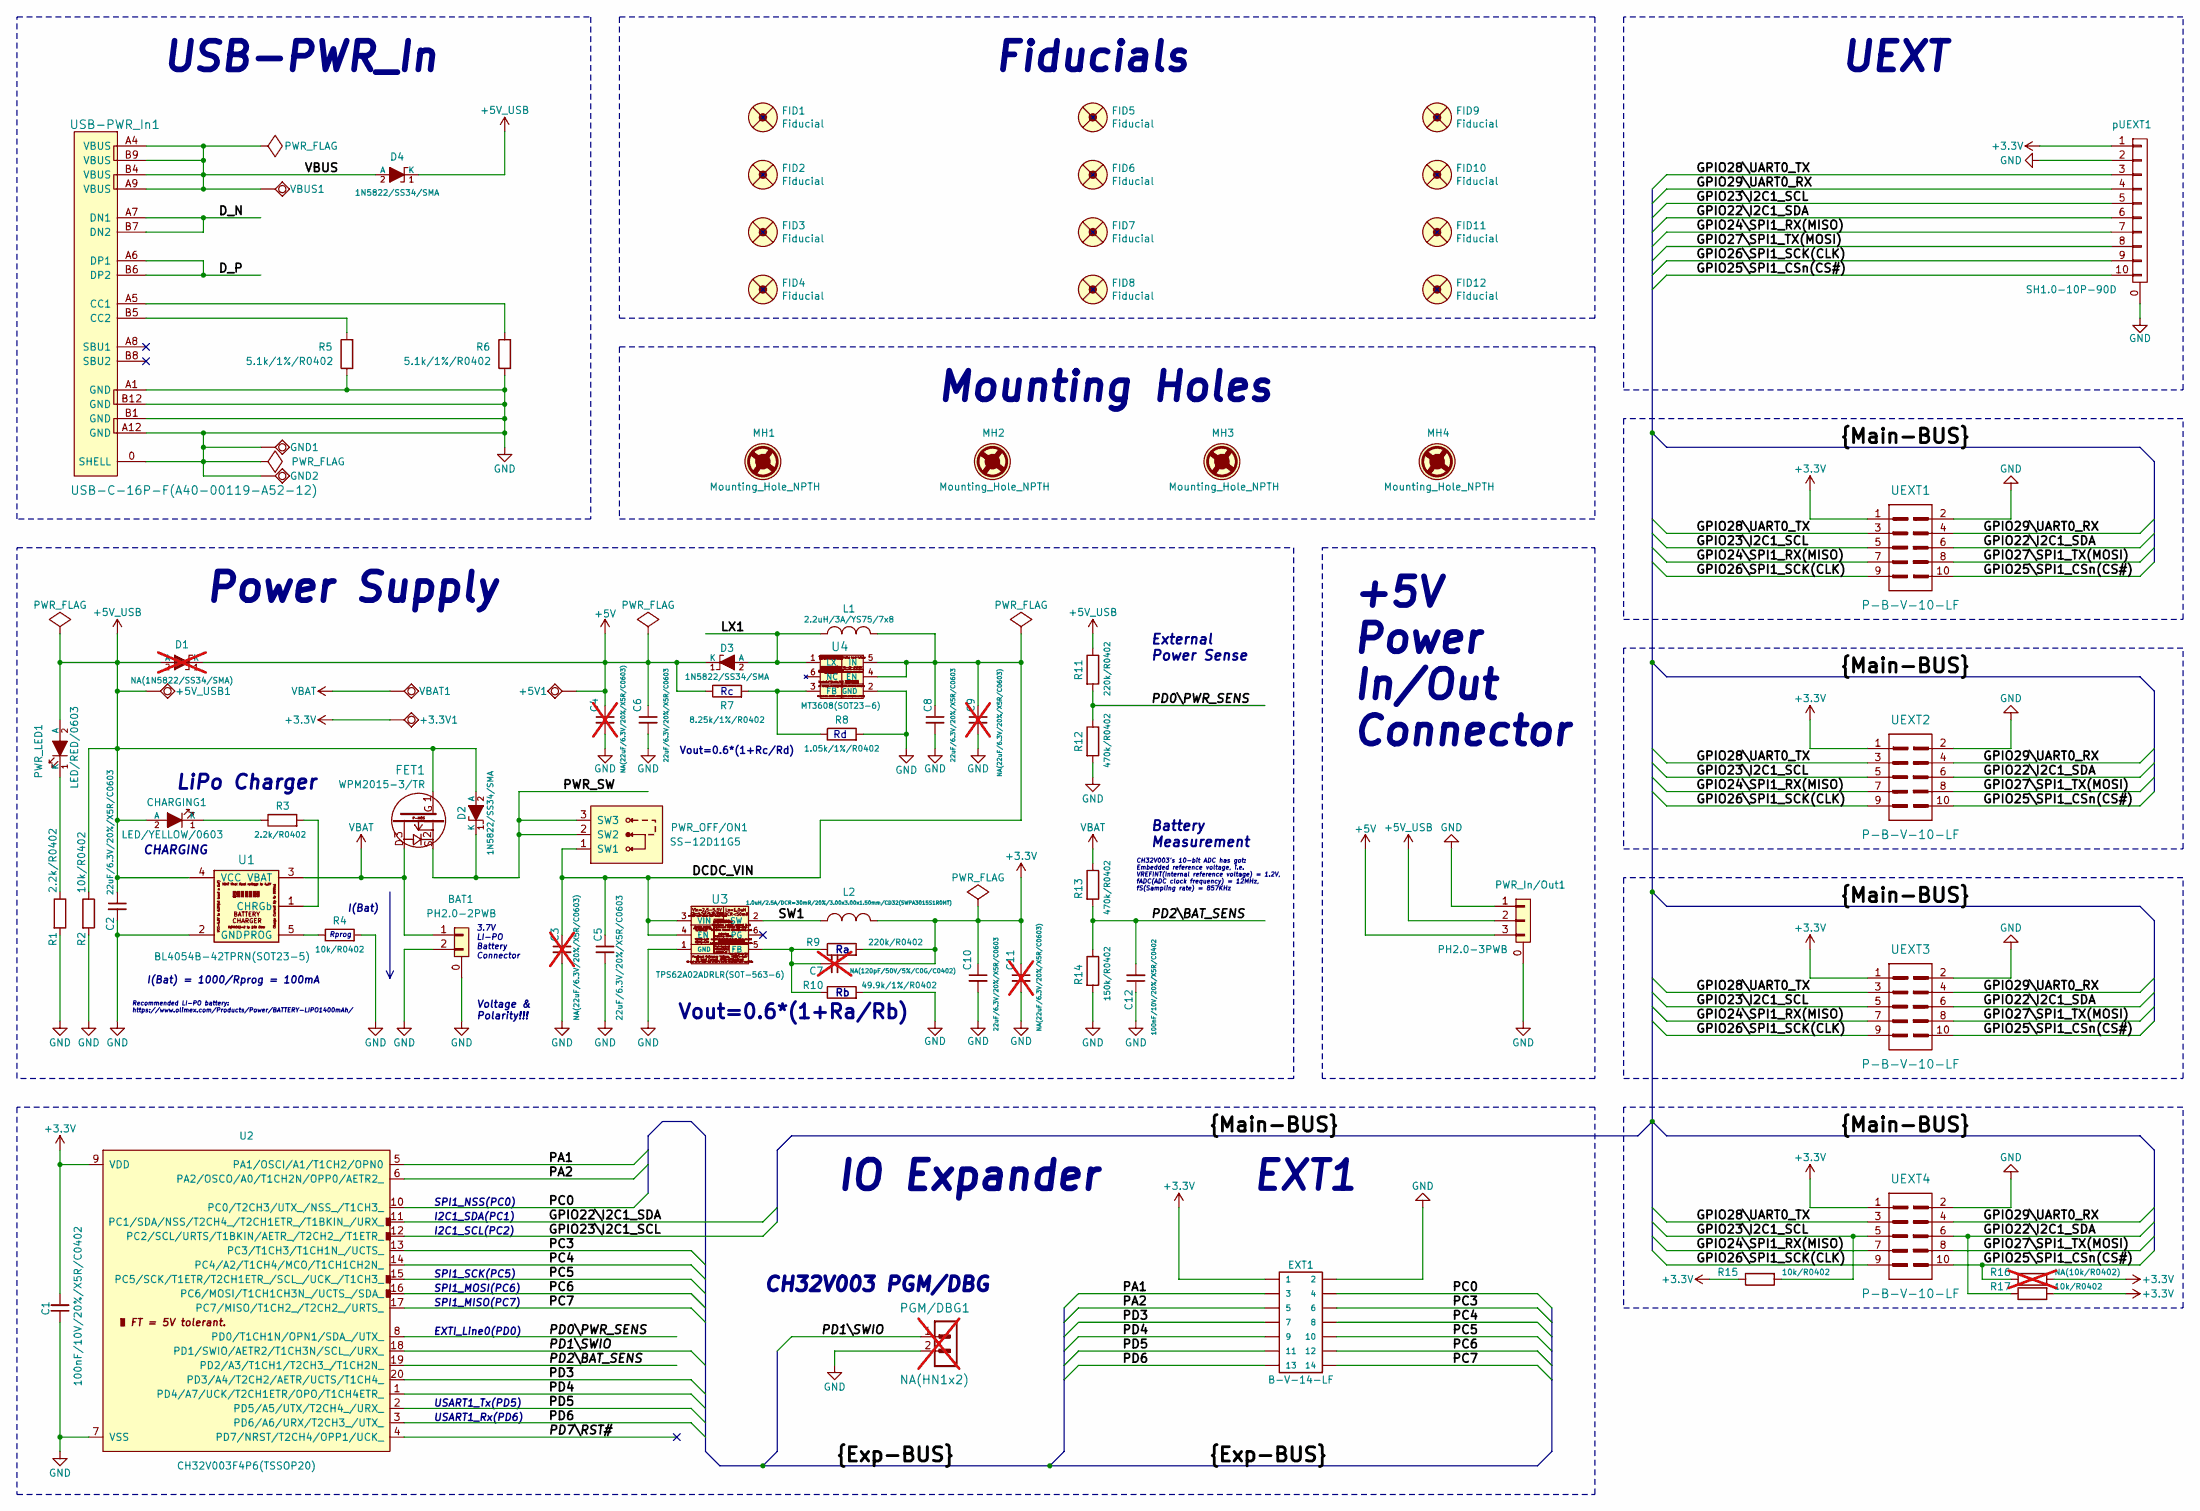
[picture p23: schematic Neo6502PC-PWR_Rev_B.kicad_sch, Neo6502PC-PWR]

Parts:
+3.3V1, +5V1, +5V_USB1: TESTPAD; TEST_PAD40x70_SQUARE
BAT1: PH2.0-2PWB
C1, C12: 100nF/10V/20%/X5R/C0402; C_0402_5MIL_DWS
C2, C5, C6, C8, C10: 22uF/6.3V/20%/X5R/C0603; C_0603_5MIL_DWS
C3, C4, C9, C11: NA(22uF/6.3V/20%/X5R/C0603); C_0603_5MIL_DWS; not fitted
C7: NA(120pF/50V/5%/C0G/C0402); C_0402_5MIL_DWS; not fitted
CHARGING1: LED/YELLOW/0603; LED_0603_KA
D1: NA(1N5822/SS34/SMA); SMA-KA; not fitted
D2, D3, D4: 1N5822/SS34/SMA; SMA-KA
EXT1: B-V-14-LF; GBH-254-SMT-14
FET1: WPM2015-3/TR; SOT23
FID1, FID2, FID3, FID4, FID5, FID7: Fiducial; Fiducial1x3_Paste
FID6, FID8, FID9, FID10, FID11, FID12: Fiducial; Fiducial1x3
GND1, GND2: TESTPAD; TEST_PAD40x70_SQUARE
L1: 2.2uH/3A/YS75/7x8; YS75_7X8MM
L2: 1.0uH/2.5A/DCR=30mR/20%/3.00x3.00x1.50mm/CD32(SWP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; CD32
MH1, MH2, MH3, MH4: Mounting_Hole_NPTH; Mounting_Hole_Drill-3.3mm_Clerance-7mm
PGM/DBG1: NA(HN1x2); HN1x2; not fitted
PWR_In/Out1: PH2.0-3PWB
PWR_LED1: LED/RED/0603; LED_0603_KA
PWR_OFF/ON1: SS-12D11G5
R1, R3: 2.2k/R0402; R_0402_5MIL_DWS
R2, R4, R15, R17: 10k/R0402; R_0402_5MIL_DWS
R5, R6: 5.1k/1%/R0402; R_0402_5MIL_DWS
R7: 8.25k/1%/R0402; R_0402_5MIL_DWS
R8: 1.05k/1%/R0402; R_0402_5MIL_DWS
R9, R11: 220k/R0402; R_0402_5MIL_DWS
R10: 49.9k/1%/R0402; R_0402_5MIL_DWS
R12, R13: 470k/R0402; R_0402_5MIL_DWS
R14: 150k/R0402; R_0402_5MIL_DWS
R16: NA(10k/R0402); R_0402_5MIL_DWS; not fitted
U1: BL4054B-42TPRN(SOT23-5); SOT-23-5
U2: CH32V003F4P6(TSSOP20); TSSOP20_Pitch-0.65mm_6.6x4.5x1.2mm
U3: TPS62A02ADRLR(SOT-563-6); SOT-563-6
U4: MT3608(SOT23-6); SOT23-6
UEXT1, UEXT2, UEXT3, UEXT4: P-B-V-10-LF; GBH-254-SMT-10
USB-PWR_In1: USB-C-16P-F(A40-00119-A52-12); USB2.0_TYPE-C(A40-00119-A52-12)_Paste
VBAT1: TESTPAD; TEST_PAD40x70_SQUARE
VBUS1: TESTPAD; TEST_PAD40x70_SQUARE
pUEXT1: SH1.0-10P-90D; SM10B-SRSS-TB

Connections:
+3.3V: +3.3V1.1 (Pad), C1.2, C7.2, C10.1, C11.1, EXT1.1, L2.2, R9.2, R15.1, R16.2, R17.2, U2.9 (VDD), UEXT1.1, UEXT2.1, UEXT3.1, UEXT4.1, pUEXT1.1
+5V: +5V1.1 (Pad), C4.1, C6.1, D1.1 (K), D3.1 (K), PWR_In/Out1.3 (P2), R7.1
+5V_USB: +5V_USB1.1 (Pad), C2.1, CHARGING1.2 (A), D1.2 (A), D2.2 (A), D4.1 (K), FET1.1, PWR_In/Out1.2, PWR_LED1.2 (A), R2.1, R11.1, U1.4 (VCC)
/DCDC_VIN: C3.1, C5.1, C8.1, C9.1, L1.2, PWR_OFF/ON1.1 (SW1), U3.3 (VIN), U3.4 (EN), U4.4 (EN), U4.5 (IN)
/D_N: USB-PWR_In1.A7 (DN1), USB-PWR_In1.B7 (DN2)
/D_P: USB-PWR_In1.A6 (DP1), USB-PWR_In1.B6 (DP2)
/GPIO22\I2C1_SDA: R17.1, U2.11 (PC1/SDA/NSS/T2CH4_/T2CH1ETR_/T1BKIN_/UR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), UEXT1.6, UEXT2.6, UEXT3.6, UEXT4.6, pUEXT1.6
/GPIO23\I2C1_SCL: R15.2, U2.12 (PC2/SCL/URTS/T1BKIN/AETR_/T2CH2_/T1ETR_), UEXT1.5, UEXT2.5, UEXT3.5, UEXT4.5, pUEXT1.5
/GPIO24\SPI1_RX(MISO): UEXT1.7, UEXT2.7, UEXT3.7, UEXT4.7, pUEXT1.7
/GPIO25\SPI1_CSn(CS#): R16.1, UEXT1.10, UEXT2.10, UEXT3.10, UEXT4.10, pUEXT1.10
/GPIO26\SPI1_SCK(CLK): UEXT1.9, UEXT2.9, UEXT3.9, UEXT4.9, pUEXT1.9
/GPIO27\SPI1_TX(MOSI): UEXT1.8, UEXT2.8, UEXT3.8, UEXT4.8, pUEXT1.8
/GPIO28\UART0_TX: UEXT1.3, UEXT2.3, UEXT3.3, UEXT4.3, pUEXT1.3
/GPIO29\UART0_RX: UEXT1.4, UEXT2.4, UEXT3.4, UEXT4.4, pUEXT1.4
/LX1: D3.2 (A), L1.1, U4.1 (LX)
/PA1: EXT1.3, U2.5 (PA1/OSCI/A1/T1CH2/OPN0)
/PA2: EXT1.5, U2.6 (PA2/OSCO/A0/T1CH2N/OPP0/AETR2_)
/PC0: EXT1.4, U2.10 (PC0/T2CH3/UTX_/NSS_/T1CH3_)
/PC3: EXT1.6, U2.13 (PC3/T1CH3/T1CH1N_/UCTS_)
/PC4: EXT1.8, U2.14 (PC4/A2/T1CH4/MCO/T1CH1CH2N_)
/PC5: EXT1.10, U2.15 (PC5/SCK/T1ETR/T2CH1ETR_/SCL_/UCK_/T1CH3_)
/PC6: EXT1.12, U2.16 (PC6/MOSI/T1CH1CH3N_/UCTS_/SDA_)
/PC7: EXT1.14, U2.17 (PC7/MISO/T1CH2_/T2CH2_/URTS_)
/PD0\PWR_SENS: R11.2, R12.1, U2.8 (PD0/T1CH1N/OPN1/SDA_/UTX_)
/PD1\SWIO: PGM/DBG1.1, U2.18 (PD1/SWIO/AETR2/T1CH3N/SCL_/URX_)
/PD2\BAT_SENS: C12.2, R13.2, R14.1, U2.19 (PD2/A3/T1CH1/T2CH3_/T1CH2N_)
/PD3: EXT1.7, U2.20 (PD3/A4/T2CH2/AETR/UCTS/T1CH4_)
/PD4: EXT1.9, U2.1 (PD4/A7/UCK/T2CH1ETR/OPO/T1CH4ETR_)
/PD5: EXT1.11, U2.2 (PD5/A5/UTX/T2CH4_/URX_)
/PD6: EXT1.13, U2.3 (PD6/A6/URX/T2CH3_/UTX_)
/PD7\RST#: U2.4 (PD7/NRST/T2CH4/OPP1/UCK_)
/PWR_SW: D2.1 (K), FET1.2, PWR_OFF/ON1.2 (SW2), PWR_OFF/ON1.3 (SW3)
/SW1: L2.1, U3.2 (SW)
/VBUS: D4.2 (A), USB-PWR_In1.A4 (VBUS), USB-PWR_In1.A9 (VBUS), USB-PWR_In1.B4 (VBUS), USB-PWR_In1.B9 (VBUS), VBUS1.1 (Pad)
GND: BAT1.0, BAT1.2, C1.1, C2.2, C3.2, C4.2, C5.2, C6.2, C8.2, C9.2, C10.2, C11.2, C12.1, EXT1.2, GND1.1 (Pad), GND2.1 (Pad), PGM/DBG1.2, PWR_In/Out1.0, PWR_In/Out1.1, R1.2, R2.2, R4.2, R5.1, R6.1, R8.2, R10.2, R12.2, R14.2, U1.2 (GND), U2.7 (VSS), U3.1 (GND), U4.2 (GND), UEXT1.2, UEXT2.2, UEXT3.2, UEXT4.2, USB-PWR_In1.0 (SHELL), USB-PWR_In1.A1 (GND), USB-PWR_In1.A12 (GND), USB-PWR_In1.B1 (GND), USB-PWR_In1.B12 (GND), pUEXT1.0, pUEXT1.2
unnamed: CHARGING1.1 (K), R3.1
unnamed: PWR_LED1.1 (K), R1.1
unnamed: R3.2, U1.1 (CHRGb)
unnamed: R4.1, U1.5 (PROG)
unnamed: C7.1, R9.1, R10.1, U3.5 (FB)
unnamed: R7.2, R8.1, U4.3 (FB)
unnamed: R6.2, USB-PWR_In1.A5 (CC1)
unnamed: R5.2, USB-PWR_In1.B5 (CC2)
VBAT: BAT1.1, FET1.3, R13.1, U1.3 (VBAT), VBAT1.1 (Pad)

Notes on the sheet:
I(Bat) = 1000/Rprog = 100mA
CHARGING
CH32V003 PGM/DBG
SPI1_MOSI(PC6)
Rprog
External Power Sense
I2C1_SCL(PC2)
SPI1_MISO(PC7)
Fiducials
EXT1
Recommended LI-PO battery: https://www.olimex.com/Products/Power/BATTERY-LIPO1400mAh/
LiPo Charger
Power Supply
I(Bat)
Mounting Holes
EXTI_Line0(PD0)
I2C1_SDA(PC1)
USART1_Rx(PD6)
Vout=0.6*(1+Rc/Rd)
Vout=0.6*(1+Ra/Rb)
SPI1_NSS(PC0)
USART1_Tx(PD5)
3.7V LI-PO Battery Connector
CH32V003's 10-bit ADC has got: Embedded reference voltage, i.e. VREFINT(Internal reference voltage) = 1.2V, fADC(ADC clock frequency) = 12MHz, fS(Sampling rate) = 857KHz
UEXT
IO Expander
+5V Power In/Out Connector
SPI1_SCK(PC5)
USB-PWR_In
Voltage & Polarity!!!
Battery Measurement

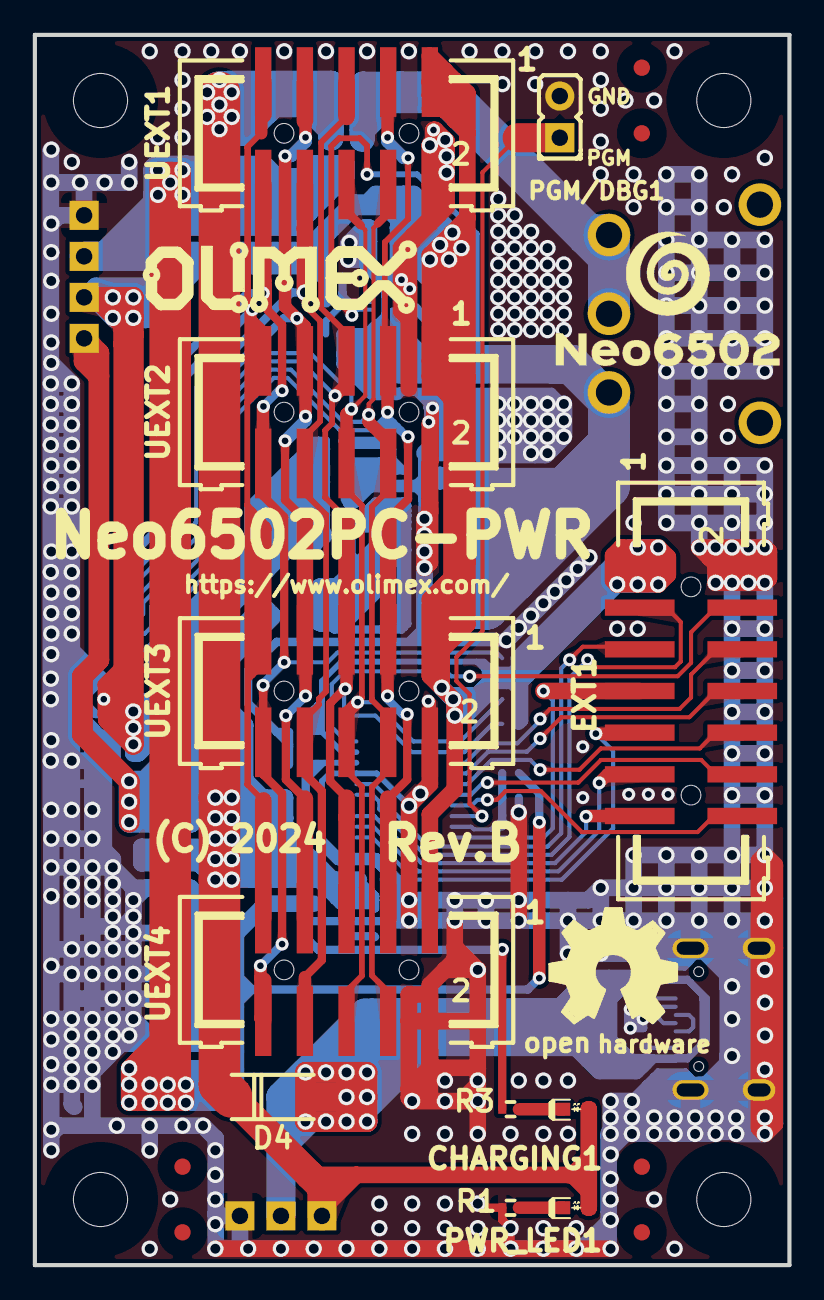
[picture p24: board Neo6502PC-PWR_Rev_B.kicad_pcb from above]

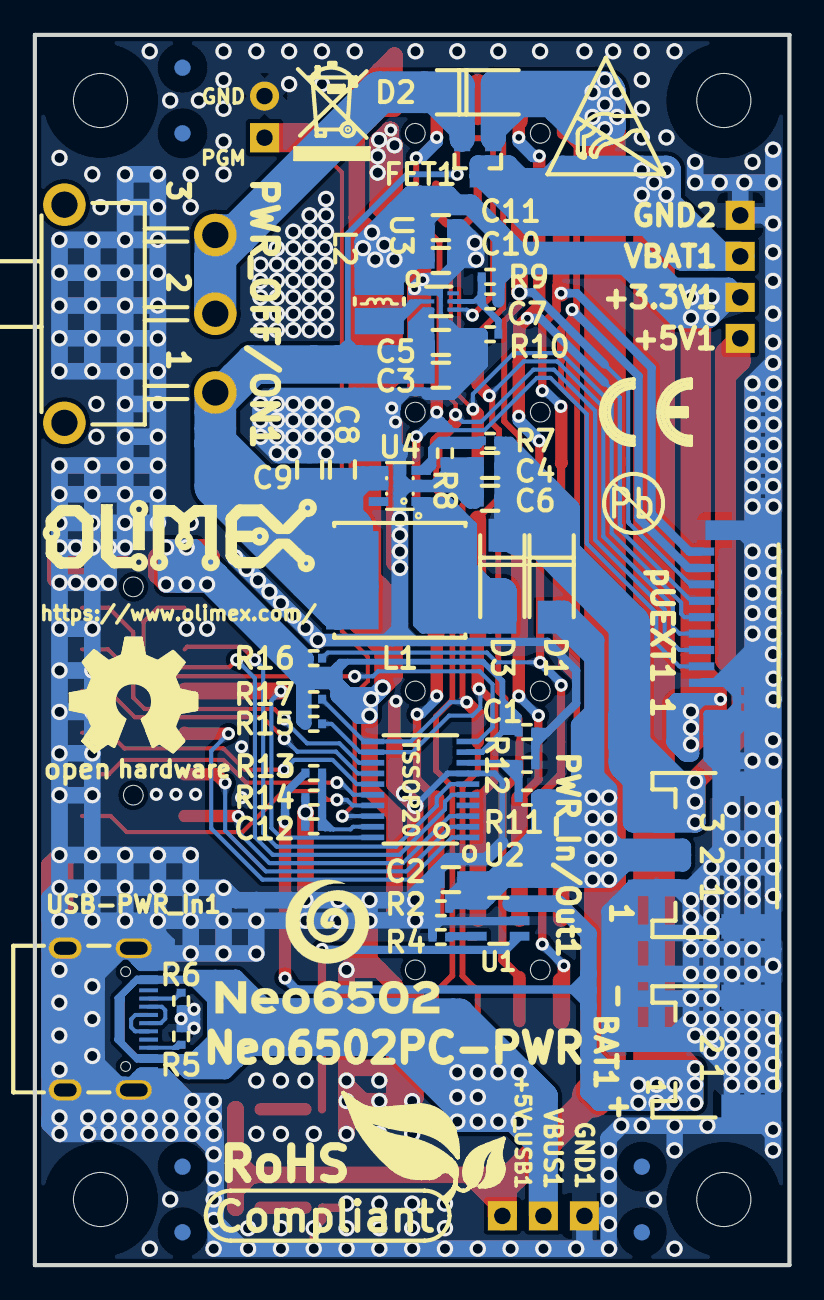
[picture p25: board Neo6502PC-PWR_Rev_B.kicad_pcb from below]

Board: 2 copper layers, 46.0 x 75.0 mm, 87 parts (63 on the bottom side), 43 nets.

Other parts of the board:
Logo_OLIMEX_TB-Bottom: Logo_OLIMEX_TB
Logo_OLIMEX_TB-Top: Logo_OLIMEX_TB
NEO_LOGO_SMALL*: LOGO; Neo6502_Sign_Small
NEO_LOGO_SMALL_Top*: LOGO; Neo6502_Sign_Small
Sign_Antistatic: Sign_Antistatic
Sign_CE: CE_Sign
Sign_OSHW_8x8, Sign_OSHW_8x8-Top: Sign_OSHW_8x8
Sign_PB-Free: Sign_PB-Free
Sign_RecycleBin: Sign_RecycleBin; Sign_RecycleBin_1
Sign_RoHS: Sign_RoHS; Sign_RoHS_1

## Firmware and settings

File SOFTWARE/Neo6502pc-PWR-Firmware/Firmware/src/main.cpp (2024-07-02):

#include <ch32v00x.h>

#include "log_debug.h"
#include "uptime.h"
#include "gpio_extender.h"

extern "C" void NMI_Handler(void)       __attribute__((interrupt("WCH-Interrupt-fast")));
extern "C" void HardFault_Handler(void) __attribute__((interrupt("WCH-Interrupt-fast")));

int main(void) {
	NVIC_PriorityGroupConfig(NVIC_PriorityGroup_2);
	SystemCoreClockUpdate();

	// Disable GPIO Alternate Functions and extrnal oscilator
	// Othewize GPIO PORT A does not work
	RCC_HSEConfig(RCC_HSE_OFF);
	GPIO_PinRemapConfig(GPIO_Remap_PA1_2, DISABLE);

	Uptime_Init();
	LOG_DEBUG_Configure(115200, USART_StopBits_1, USART_Parity_No);

	LOG_DEBUG(EOL "System Clock: %ld" EOL, SystemCoreClock);

	GPIO_Extender::Setup();

	while (1) {
		// GPIO_Extender::pinBlink(4, 1000);
	}

}

void NMI_Handler(void) {
	LOG_DEBUG("NMI_Handler()" EOL);
}

void HardFault_Handler(void) {
	LOG_DEBUG("HardFault_Handler()" EOL);
	while (1) {
		
	}
}

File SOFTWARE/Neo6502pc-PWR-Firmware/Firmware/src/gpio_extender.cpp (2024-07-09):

#include "gpio_extender.h"

#include "log_debug.h"
#include "uptime.h"
#include "adc.h"

/* Extender GPIO Mapping */
typedef struct {
	GPIO_TypeDef* port;
	uint16_t pin;
} ext_GPIO_Map_Type;

const ext_GPIO_Map_Type ext_GPIO_Map[EXT_GPIO_PIN_COUNT] = {
	{},                     //
	{},                     // +3.3V #1
	{},                     // GND   #2
	{GPIOA, GPIO_Pin_1},    // PA1   #3
	{GPIOC, GPIO_Pin_0},    // PC0   #4
	{GPIOA, GPIO_Pin_2},    // PA2   #5
	{GPIOC, GPIO_Pin_3},    // PC3   #6
	{GPIOD, GPIO_Pin_3},    // PD3   #7
	{GPIOC, GPIO_Pin_4},    // PC4   #8
	{GPIOD, GPIO_Pin_4},    // PD4   #9
	{GPIOC, GPIO_Pin_5},    // PC5   #10
	{GPIOD, GPIO_Pin_5},    // PD5   #11
	{GPIOC, GPIO_Pin_6},    // PC6   #12
	{GPIOD, GPIO_Pin_6},    // PD6   #13
	{GPIOC, GPIO_Pin_7},    // PC7   #14
	{GPIOD, GPIO_Pin_0},    // PD0   #15 PWR_SENS
};

// Initial GPIO extender cofiguration
// Odd pins  - input pull down
// Even pins - output push pull
ext_GPIO_Mode_Type ext_GPIO_Mode[EXT_GPIO_PIN_COUNT] = {
	ext_GPIO_Mode_OOD,    //
	ext_GPIO_Mode_IPD,    // +3.3V #1
	ext_GPIO_Mode_IPD,    // GND   #2
	ext_GPIO_Mode_IPD,    //       #3
	ext_GPIO_Mode_IPD,    //       #4
	ext_GPIO_Mode_IPD,    //       #5
	ext_GPIO_Mode_IPD,    //       #6
	ext_GPIO_Mode_IPD,    //       #7
	ext_GPIO_Mode_IPD,    //       #8
	ext_GPIO_Mode_IPD,    //       #9
	ext_GPIO_Mode_IPD,    //       #10
	ext_GPIO_Mode_IPD,    //       #11
	ext_GPIO_Mode_IPD,    //       #12
	ext_GPIO_Mode_IPD,    //       #13
	ext_GPIO_Mode_IPD,    //       #14
	ext_GPIO_Mode_IF,     //       #15 PWR_SENS
};

// Initial GPIO Extender data
uint8_t ext_GPIO_Data[EXT_GPIO_PIN_COUNT] = {
	0x00,    //
	0x01,    // +3.3V #1
	0x00,    // GND   #2
	0x00,    //       #3
	0x00,    //       #4
	0x00,    //       #5
	0x00,    //       #6
	0x00,    //       #7
	0x00,    //       #8
	0x00,    //       #9
	0x00,    //       #10
	0x00,    //       #11
	0x00,    //       #12
	0x00,    //       #13
	0x00,    //       #14
	0x00,    //       #15 PWR_SENS
};

uint16_t GPIO_Extender::Version() {
	return EXT_GPIO_REG_API_MAJOR * 256 + EXT_GPIO_REG_API_MINOR;
}

void GPIO_Extender::Setup(uint8_t addr) {
	i2c_address = addr;
	Begin();
}

void GPIO_Extender::Begin() {
	// GPIO configuration
	RCC_APB2PeriphClockCmd(RCC_APB2Periph_GPIOA, ENABLE);
	RCC_APB2PeriphClockCmd(RCC_APB2Periph_GPIOC, ENABLE);
	RCC_APB2PeriphClockCmd(RCC_APB2Periph_GPIOD, ENABLE);

	for (uint8_t pin=EXT_GPIO_PIN_FIRST; pin < EXT_GPIO_PIN_COUNT; pin++) {
		pinConfig(pin, ext_GPIO_Mode[pin], true);
	}

	// BAT_SENSE configuration
	if (ADC_Channel_Init(EXT_GPIO_BATSENS_PORT, EXT_GPIO_BATSENS_PIN, ADC_TIMEOUT_MS) == ADC_SUCCESS) {
		LOG_DEBUG("GPIO_Extender: BAT_SENSE configured" EOL);
	} else {
		LOG_DEBUG("GPIO_Extender:BAT_SENSE configuration FAILED" EOL);
	}
	
	I2C_Slave_Setup(i2c_address, i2c_registers, sizeof(i2c_registers), preRegRead, onRegRead, onRegWrite);

	LOG_DEBUG("GPIO_Extender: Initialized. Version %d.%d" EOL, EXT_GPIO_API_MAJOR, EXT_GPIO_API_MINOR);
}

void GPIO_Extender::preRegRead(uint8_t reg) {
	uint8_t selected_pin = i2c_registers[EXT_GPIO_REG_SELECT];
	switch (reg) {
		case EXT_GPIO_REG_API_MAJOR:
			i2c_registers[EXT_GPIO_REG_API_MAJOR] = EXT_GPIO_API_MAJOR;
		break;

		case EXT_GPIO_REG_API_MINOR:
			i2c_registers[EXT_GPIO_REG_API_MINOR] = EXT_GPIO_API_MINOR;
		break;

		case EXT_GPIO_REG_DATA:
			if (isPinInput(selected_pin)) {
				i2c_registers[EXT_GPIO_REG_DATA] = getPin(selected_pin);
			}
		break;

		case EXT_GPIO_REG_ALL_DATA_MSB:
			for (uint8_t pin=0x08; pin < EXT_GPIO_PIN_COUNT; pin++) {
				getPin(pin);
			}
		break;

		case EXT_GPIO_REG_ALL_DATA_LSB:
			for (uint8_t pin=EXT_GPIO_PIN_FIRST; pin < 0x08; pin++) {
				getPin(pin);
			}
		break;

		case EXT_GPIO_REG_BATSENS_PERCENT:
			getBatPercent();
		break;

		case EXT_GPIO_REG_BATSENS_MSB:
			getBatVoltage();
		break;

		case EXT_GPIO_REG_BATSENS_LSB:
			getBatVoltage();
		break;
	}
}
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

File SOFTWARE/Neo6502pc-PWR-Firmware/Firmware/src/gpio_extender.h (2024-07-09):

#ifndef __GPIO_EXTENDER_H
#define __GPIO_EXTENDER_H

#include <ch32v00x.h>

#include "i2c_slave.h"

#define EXT_GPIO_PIN_FIRST   3
#define EXT_GPIO_PIN_LAST    15
#define EXT_GPIO_PIN_PWRSENS 15
#define EXT_GPIO_PIN_COUNT   16

#ifdef LOD_DEBUG_ENABLE
#define EXT_GPIO_PIN_SKIP 11
#else
#define EXT_GPIO_PIN_SKIP -1
#endif

#define EXT_GPIO_I2C_ADDR            0x33

#define EXT_GPIO_API_MAJOR           1
#define EXT_GPIO_API_MINOR           1

#define EXT_GPIO_REG_API_MAJOR       0x00
#define EXT_GPIO_REG_API_MINOR       0x01
#define EXT_GPIO_REG_SELECT          0x02
#define EXT_GPIO_REG_CONFIG          0x03
#define EXT_GPIO_REG_DATA            0x04
#define EXT_GPIO_REG_ALL_DATA_MSB    0x05
#define EXT_GPIO_REG_ALL_DATA_LSB    0x06
#define EXT_GPIO_REG_BATSENS_PERCENT 0x07
#define EXT_GPIO_REG_BATSENS_MSB     0x08
#define EXT_GPIO_REG_BATSENS_LSB     0x09
#define EXT_GPIO_REG_COUNT           0x0A

// BATSENS = 1000 * R14 * VBAT / (R14 + R13)
// VBAT range 4.1V - 3.3V
#define EXT_GPIO_BATSENS_MIN         800
#define EXT_GPIO_BATSENS_MAX         996

#define EXT_GPIO_BATSENS_PORT        GPIOD
#define EXT_GPIO_BATSENS_PIN         GPIO_Pin_2
#define EXT_GPIO_BATSENS_CHANNEL     ADC_Channel_3

/* Extender GPIO Mode enumeration */
typedef enum {
	ext_GPIO_Mode_OOD = 0x00,
	ext_GPIO_Mode_OPP = 0x01,

	ext_GPIO_Mode_IF  = 0x80,
	ext_GPIO_Mode_IPD = 0x81,
	ext_GPIO_Mode_IPU = 0x82,
} ext_GPIO_Mode_Type;

class GPIO_Extender {
protected:
	inline static uint8_t i2c_address = 0x33;

	/* 
		Registers

		0x00 - API version (major)
		0x01 - API version (minor)

		0x02 - pin select [3-14]

		0x03 - pin config
			0x00 - out - OD
			0x01 - out - PP 
			
			0x80 - in - float
			0x81 - in - PD
			0x82 - in - PU
		
		0x04 - data read / write

		0x05, 0x06 - Pins as bits

		0x07 - BATSENS percent

		0x08, 0x09 - BATSENS mV
	*/
	inline static volatile uint8_t i2c_registers[EXT_GPIO_REG_COUNT] = {0x00, 0x00, 0x00, 0x00, 0x00, 0x00, 0x00, 0x00, 0x00, 0x00};

protected:
	static void Begin();
	static void setData(uint8_t pin, uint8_t value);
	static void setPin(uint8_t pin, uint8_t value);
	static uint8_t getPin(uint8_t pin);
	static uint8_t getBatPercent();
	static uint16_t getBatVoltage(bool average = false, uint8_t count = 20);
public:
	static uint16_t Version();

	static void Setup(uint8_t addr = EXT_GPIO_I2C_ADDR);

	static void preRegRead(uint8_t reg);
	static void onRegRead(uint8_t reg);
	static void onRegWrite(uint8_t reg, uint8_t length);
	
	static bool isPinOutOfRange(uint8_t pin);
	static bool isPinOutput(uint8_t pin);
	static bool isPinInput(uint8_t pin);

	static void pinConfig(uint8_t pin, ext_GPIO_Mode_Type mode, bool initial = false);
	static void pinBlink(uint8_t pin, int time_ms);

	GPIO_Extender() = delete;
};

#endif /* __GPIO_EXTENDER_H */

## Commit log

2024-06-25 initial upload
    [Neo6502PC-CPU_Rev_B-B_Cu.gbr, Neo6502PC-CPU_Rev_B-B_Mask.gbr, Neo6502PC-CPU_Rev_B-B_Paste.gbr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]
2024-07-09 FIX: BAT_SENS percent calibration
    Changed EXT_GPIO_BATSENS_MIN and EXT_GPIO_BATSENS_MAX values
    [gpio_extender.h]
2024-07-09 Improved ADC measurement
    Added possibility to average several consecutive measurements for better precision

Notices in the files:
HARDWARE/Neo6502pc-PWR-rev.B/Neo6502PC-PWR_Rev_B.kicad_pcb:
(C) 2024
